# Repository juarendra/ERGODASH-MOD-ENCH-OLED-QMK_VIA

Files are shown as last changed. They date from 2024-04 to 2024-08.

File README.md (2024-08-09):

# Ergodash-Mod-QMK-VIA
This is MOD of ergodash, the normal ergodash just have Swith MX. This mod is for add Encoder, Oled and make it hotswapable with Khail Hotswap

## Table of Content
* [Product Specsification](#product-specsification)
* [Download VIA](#download-via)
* [Load JSON File](#Load-JSON-File)
* [Link Keycode QMK](#Link-keycode-qmk)
* [Tutorial VIA Usage](#tutorial-via-usage)
* [Cara Setting Knob](#cara-setting-knob)
* [How To use MACRO](#how-to-use-macro)
* [Preview Hardware](#preview-hardware)
* [Preview VIA](#preview-via)
* [Cara Update/Upgrade Firmware](#cara-update/upgrade-firmware)
* [Documentation](#documentation)
  * [Pinout Diagram](#pinout-diagram)
  * [Dimension](#dimension)
  * [BOM](#bom)
  * [Schematic](#schematic)
  * [Example Program](#examples-program)
* [FAQ](#FAQ)

## Product Specsification
- Arduino Pro Micro Type C as Microcontroller
- QMK Firmware
- Support VIA, all key and knob can proggrammed
- RGB Underglow
- 4x Layer 
- Hotswap Switch
- 3D Case 
- Ergodash Profile

## Download VIA
Link Download VIA(CHOSEE BASED YOUR OS) : https://github.com/the-via/releases/releases
VIA WEB VERSION : https://usevia.app/

## Load JSON File
or you can load manually json file like a library for detect this macropad
- Connect your macropad to PC
- Open VIA
- In Tab Setting, enable "Show Design Tab"
- Open Design Tab
- Load file with name "NEW_ErgoDash_4key_V3_mod_positron_elektronik.json" 
- Open Configure Tab to setting your macropad
- If nothing happend , do it again from first 

## Link Keycode QMK
- mouse : https://github.com/qmk/qmk_firmware/blob/master/docs/feature_mouse_keys.md
- keyboard : https://github.com/qmk/qmk_firmware/blob/master/docs/keycodes.md

## Tutorial VIA Usage
- https://docs.keeb.io/via

## Cara Setting Knob
- Untuk melakukan setting di knob perlu memasukan command berupa keycode qmk, Jadi cara nya sama dengan melakuykan setting dengan Any key seperti petunjuk pada link berikut: 
https://docs.keeb.io/via

Here's some examples:

- LALT(KC_TAB) - Sends Alt-Tab
- LCTL(KC_C) - Sends Ctrl-C
- LGUI(KC_C) - Sends Cmd-C or Win-C
- LSFT(LCTL(KC_END)) - Sends Shift-Ctrl-End
- MO(1) - Momentarily turn on layer 1
- LCA(KC_DEL) - Sends Ctrl-Alt-Del
- MT(MOD_RSFT, KC_ENT) - Sends Shift if held, Enter if tapped
- MACRO (0) - macro 0

## How To use MACRO
you can read on [this file](https://github.com/juarendra/STREAMPAD-QMK-VIA/blob/main/DOC/MACRO%20VIA%20USAGE.pdf)
or you can read on this [web](https://www.keychron.com/blogs/archived/how-to-use-via-to-program-your-keyboard)
or you can see video [youtube](https://youtu.be/GtSeo69Y0Zw)

## Preview Hardware
<p align="center">
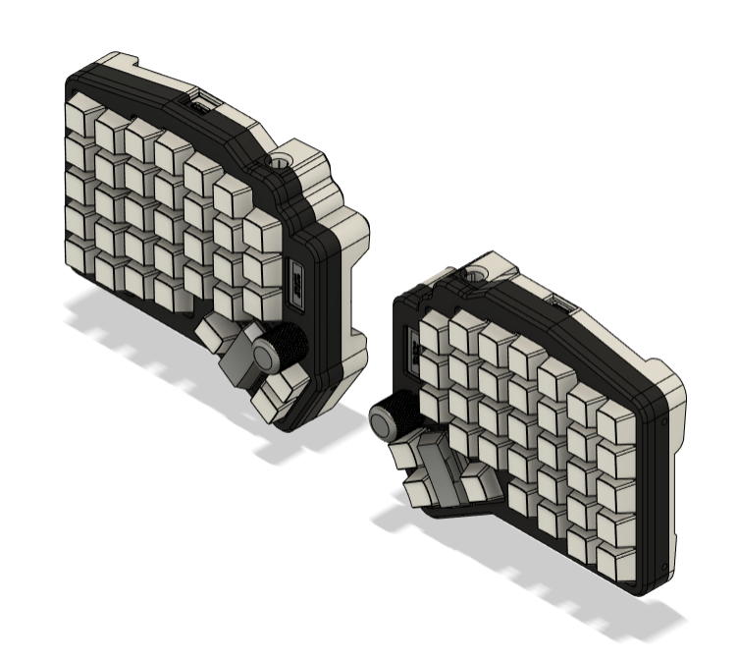
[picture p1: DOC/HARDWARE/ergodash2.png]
  
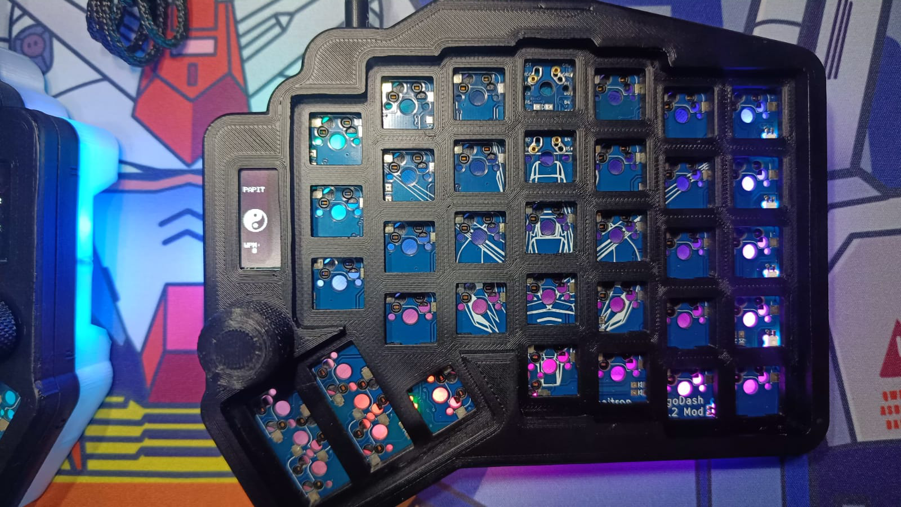
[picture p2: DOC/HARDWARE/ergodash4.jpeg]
  
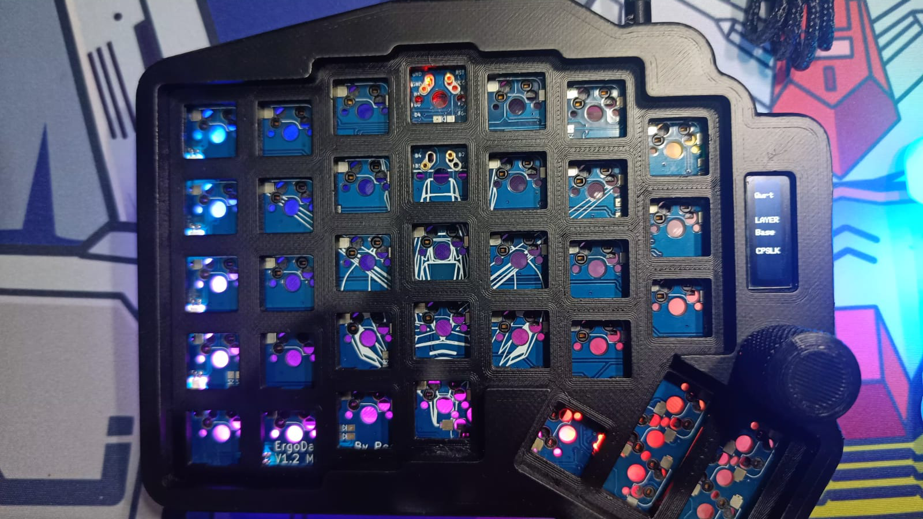
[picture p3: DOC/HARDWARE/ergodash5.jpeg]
  
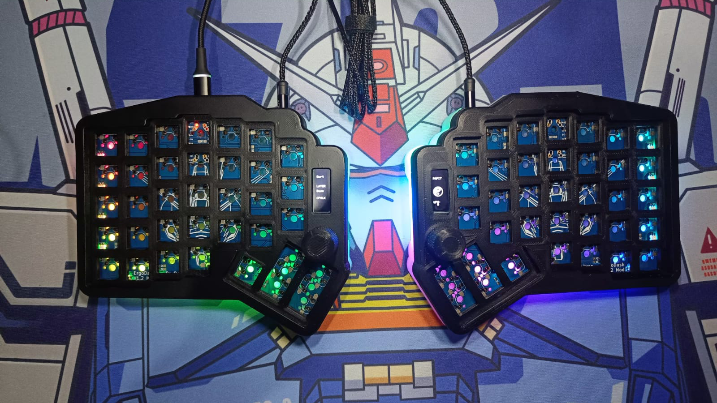
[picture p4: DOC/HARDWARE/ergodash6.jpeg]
  
</p>

## Preview VIA

https://github.com/juarendra/Zeapad-Pro-QMK-VIA/assets/43043633/afd7e68e-0a54-4b18-be12-b96c0f13611a

## Documentation
### Pinout Diagram
### Dimension
[Dimension File](https://github.com/juarendra/ERGODASH-MOD-ENCH-OLED-QMK_VIA/blob/main/Hardware/Dimension_Ergodash.pdf)
### BOM
### Schematic
[Schematic File](https://github.com/juarendra/ERGODASH-MOD-ENCH-OLED-QMK_VIA/blob/main/Hardware/ErgoDash_Schematic.pdf)
### Example Program
[Example Firmware](hhttps://github.com/juarendra/ERGODASH-MOD-ENCH-OLED-QMK_VIA/tree/main/FIRMWARE)
## FAQ

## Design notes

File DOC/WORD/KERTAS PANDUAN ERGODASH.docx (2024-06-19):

1. Untuk Documentasi Lengkapnya anda dapat membuka link google drive dibawah ini

https://github.com/juarendra/ERGODASH-MOD-ENCH-OLED-QMK_VIA

2. Lihat dahulu video untuk mengetahui cara pengunaan macropad dengan software VIA
3. Fungsi file file di google drive
a. Link Keycode.txt = berisi link yang menunjukan list keycode yang dapat digunakan dalam melakukan setting keymap
b. TUTORIAL MACRO ON VIA CONFIGURATOR.txt = berisi link tutorial cara membuat macro di software vial
c. LINK TUTORIAL PENGGUNAAN.txt = berisi link video tutorial penggunaan
d. TUTORIAL MEMBUAT TOMBOL PINDAH LAYER.txt = berisi panduan untuk merubah fungsi tombol sebagai trigger memindahkan layer
e. ErgoDash_mod_positron.json = json file untuk load di VIA

Untuk panduan lainnya menggunakan software via ada dapat membacanya disini https://docs.keeb.io/via

Pada via hanya dapat menyimpan maks 15 macro di seluruh layer. Ada beberapa trik untuk memaksimalkannya. Jika macro anda hanya kombinasi sederhana seperti CTRL + ALT + DEL maka anda dapat menggunakan fitur ANY keys pada tab special seperti dibawah

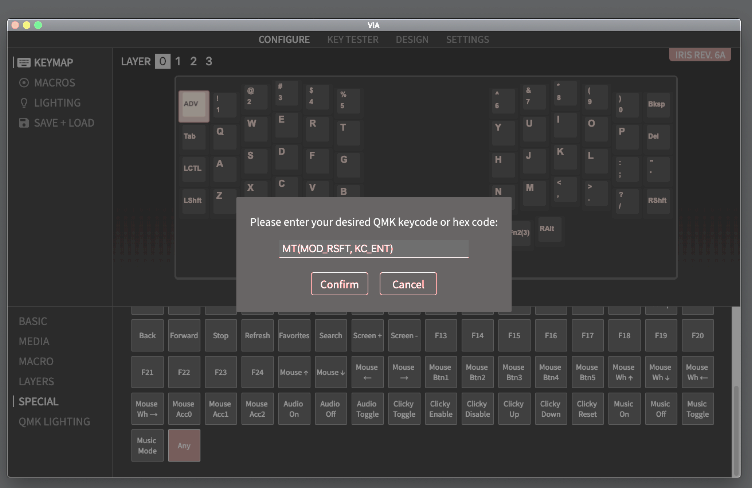
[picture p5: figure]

Untuk jelasnya anda dapat membacanya di https://docs.keeb.io/via

Cara Menggunakan Software VIA Pada Macropad

1. Colok dahulu Macropad pada PC
2. Buka Aplikasi VIA
3. Pada Tab Setting , aktifkan “Show Design Tab”
4. Buka Tan Design
5. Load file extension “ErgoDash_mod_positron.json” di google drive yang di berikan
6. Buka tab Configure untuk melakukan setting
7. Jika masih muncul gambar searching, maka ulangi lagi load json file

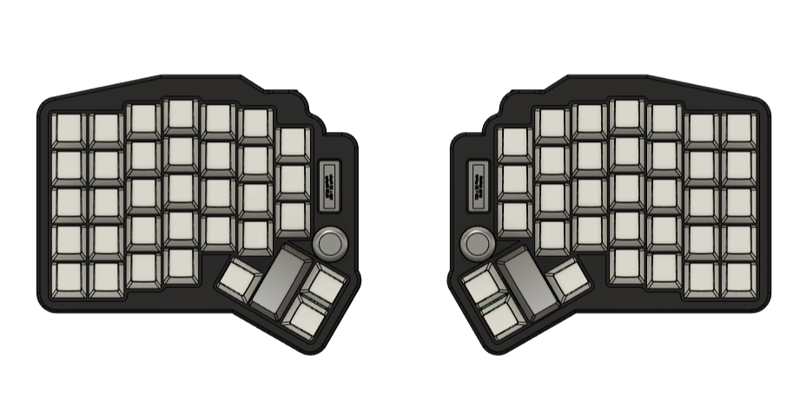
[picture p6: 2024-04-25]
DOC/HARDWARE/ergodash1.png

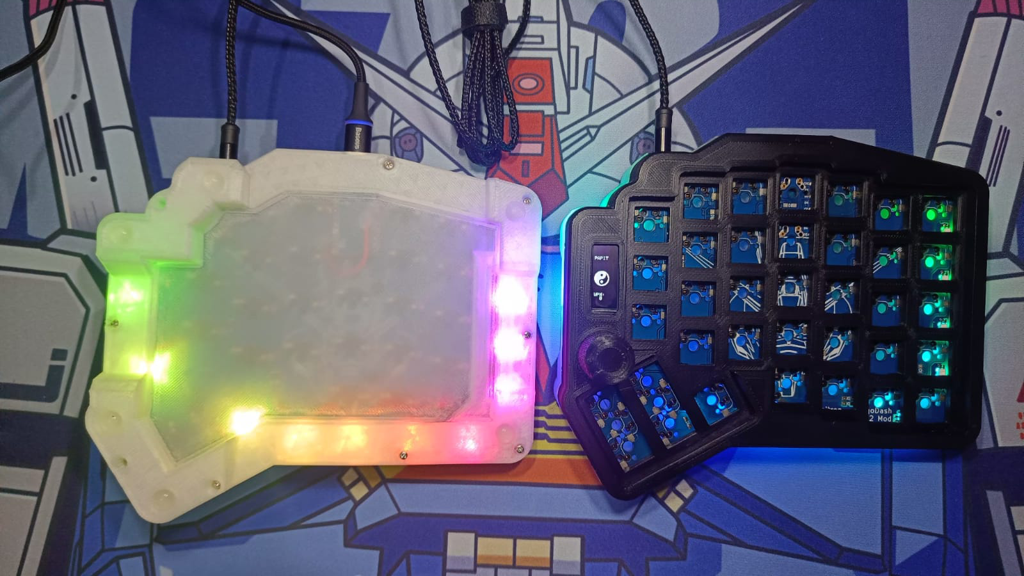
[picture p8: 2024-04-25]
DOC/HARDWARE/ergodash3.jpeg

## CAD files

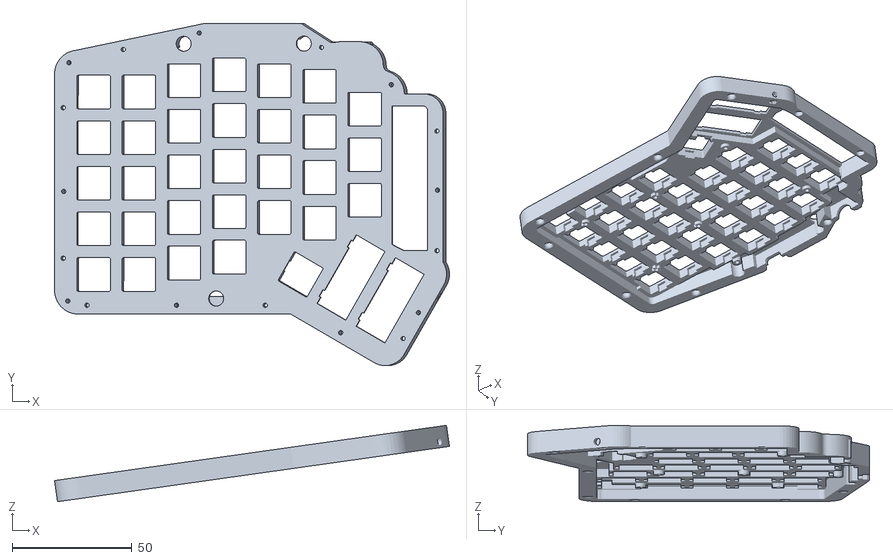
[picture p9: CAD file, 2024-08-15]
Hardware/3DCase/left/1. Ergodash_kiri_middle.stl
165.0 x 142.9 x 31.9

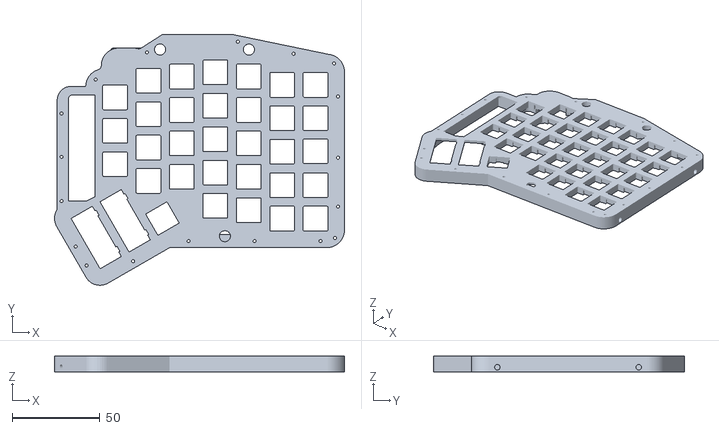
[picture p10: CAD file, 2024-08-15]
Hardware/3DCase/right/1. Ergodash_kanan_middle.stl
165.4 x 142.9 x 8.89

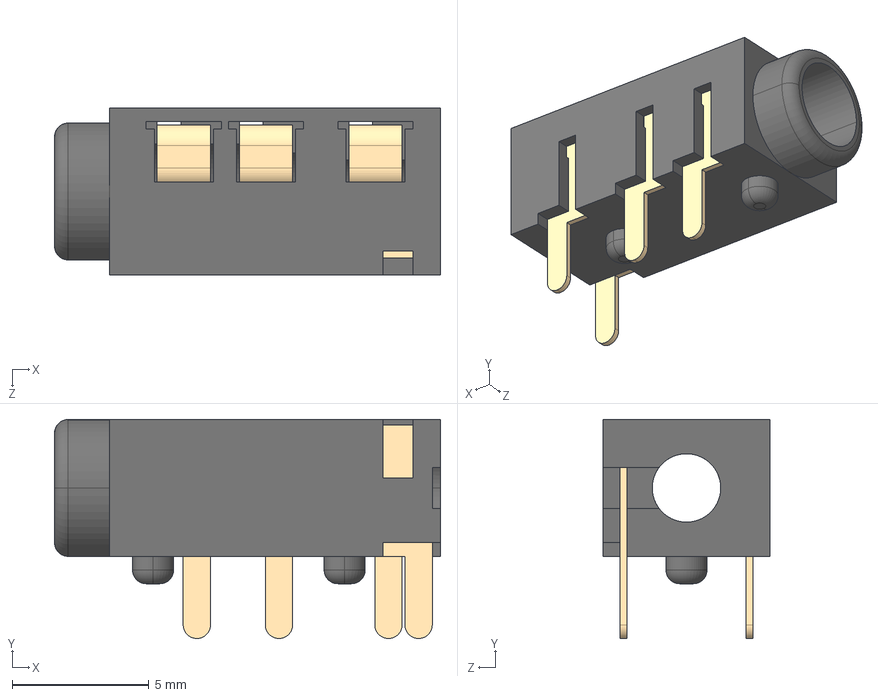
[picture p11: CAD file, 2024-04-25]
Hardware/PCB/Rev1.2/3d/PJ320A.STEP
14.1 x 8.00 x 6.10 mm
PJ320A蝶褲
PJ320A-Pin-A x 3
PJ320A-Pin-B

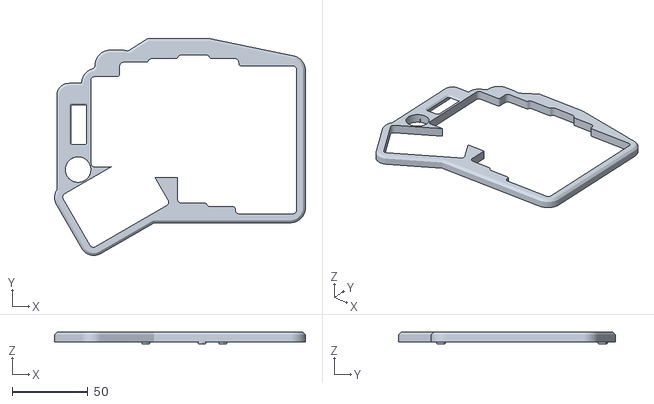
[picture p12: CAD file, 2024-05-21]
Hardware/3DCase/left/1. Ergodash_kiri_atas.stl
165.4 x 142.9 x 7.62

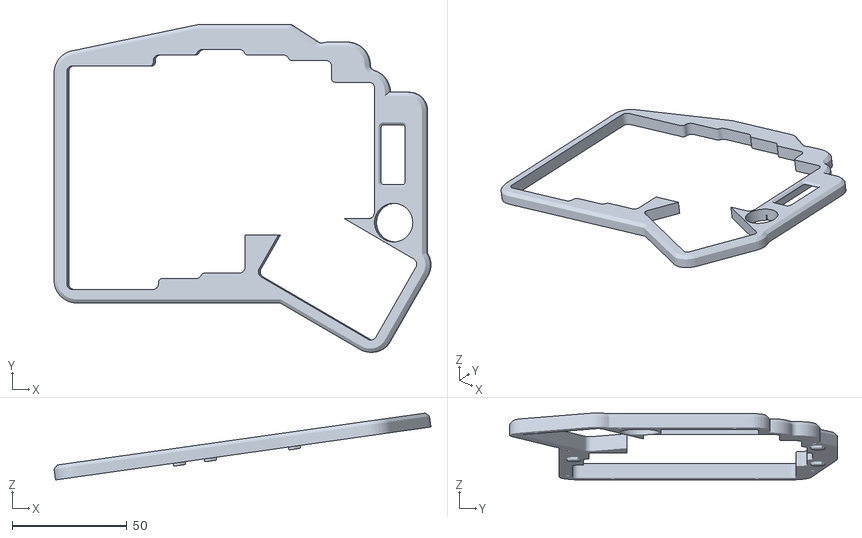
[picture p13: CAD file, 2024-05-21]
Hardware/3DCase/right/1. Ergodash_kanan_atas.stl
164.4 x 142.9 x 29.2

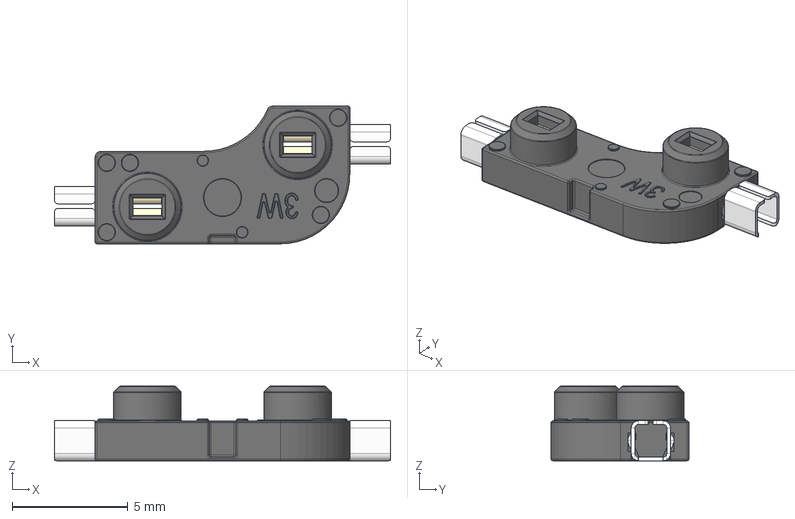
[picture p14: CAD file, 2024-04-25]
Hardware/PCB/Rev1.2/3d/Kailh Hotswap MX v22.step
14.5 x 5.95 x 3.22 mm

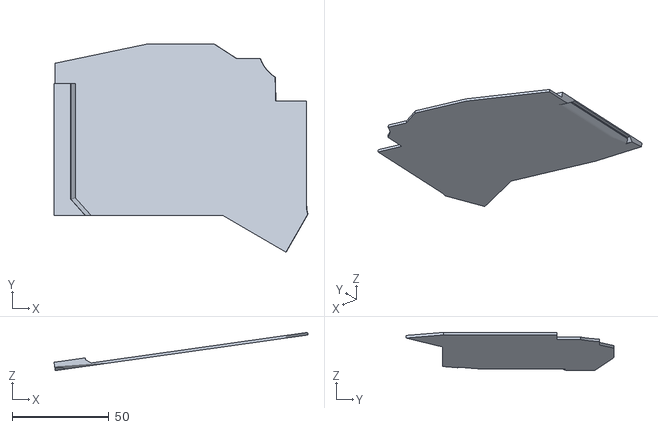
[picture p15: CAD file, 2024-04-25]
Hardware/3DCase/left/1. Ergodash_kiri_bottom2.stl
131.0 x 107.4 x 19.7

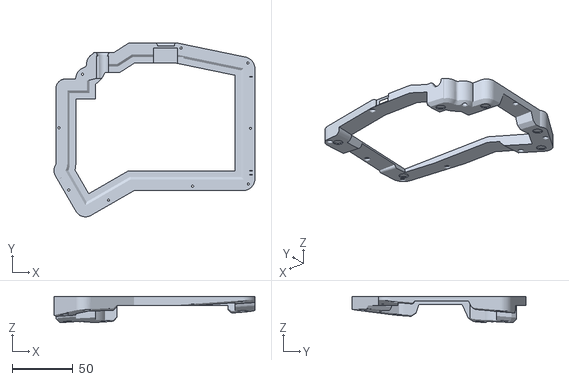
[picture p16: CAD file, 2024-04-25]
Hardware/3DCase/right/1. Ergodash_kanan_bottom1.stl
165.4 x 142.9 x 21.5

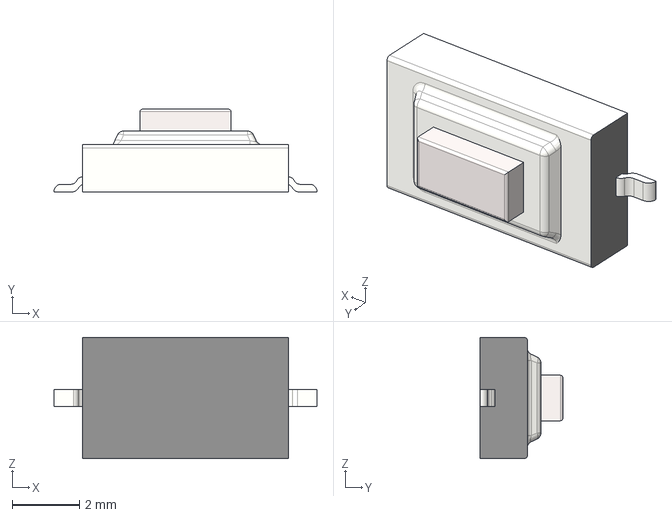
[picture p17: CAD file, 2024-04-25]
Hardware/PCB/Rev1.2/3d/TactileButton(6x3,5mm)_SMD.stp
7.80 x 2.45 x 3.60 mm

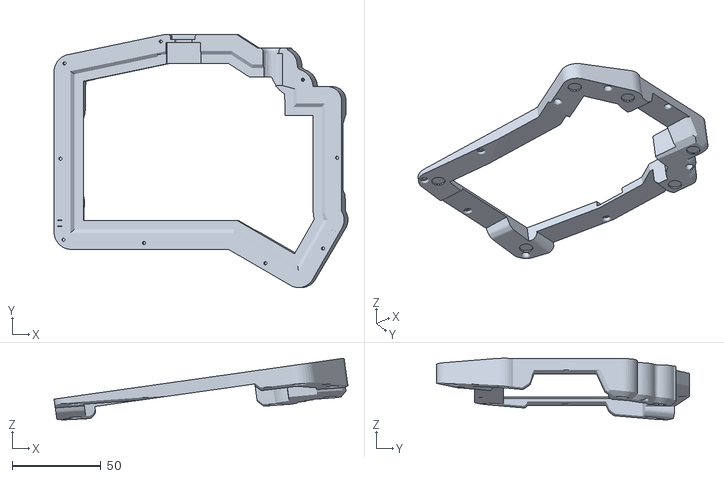
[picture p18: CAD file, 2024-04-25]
Hardware/3DCase/left/1. Ergodash_kiri_bottom1.stl
165.9 x 142.9 x 34.8

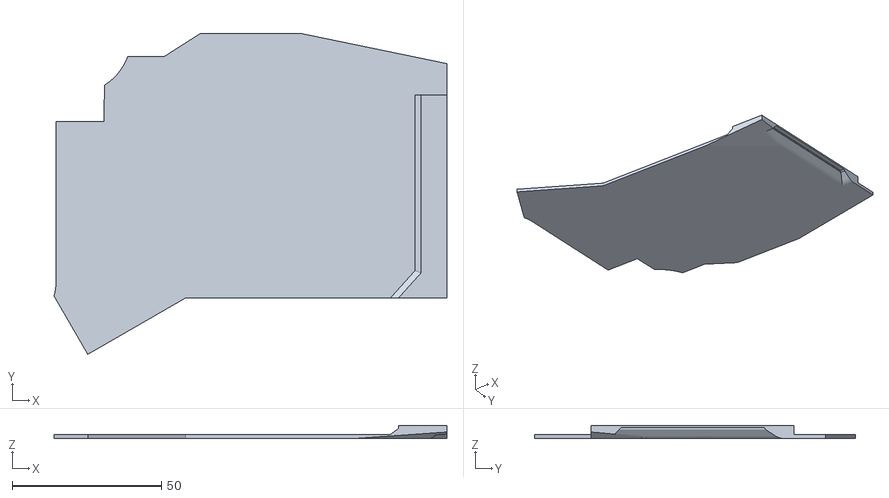
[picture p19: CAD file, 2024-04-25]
Hardware/3DCase/right/1. Ergodash_kanan_bottom2.stl
131.7 x 107.4 x 4.35

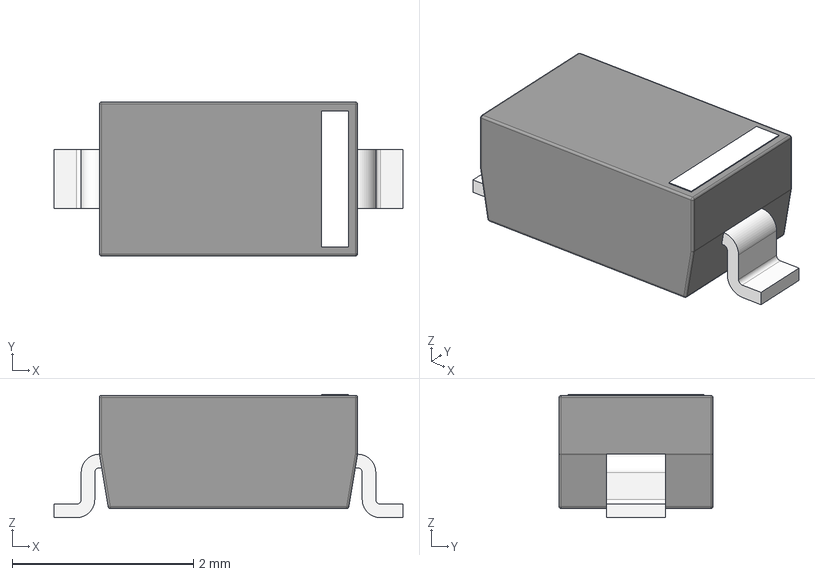
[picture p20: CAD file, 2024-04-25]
Hardware/PCB/Rev1.2/3d/SOD-123.step
3.85 x 1.70 x 1.36 mm

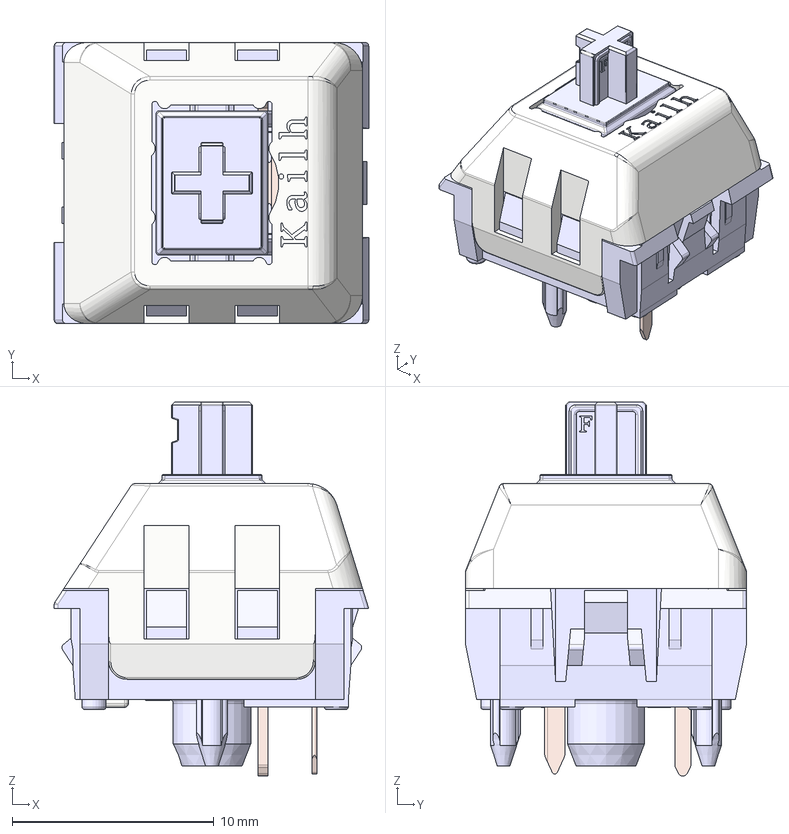
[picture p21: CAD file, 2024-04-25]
Hardware/PCB/Rev1.2/3d/Kailh Polia.step
15.6 x 14.0 x 18.5 mm
Housing
ThickContact
SpringContact
Stem
Lid

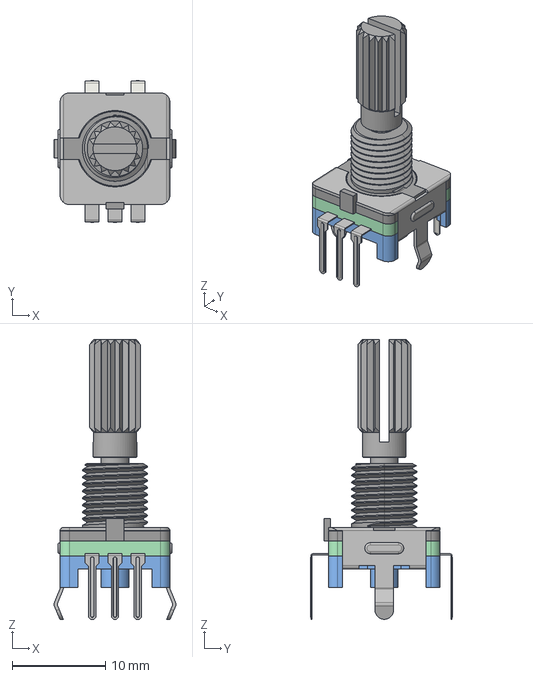
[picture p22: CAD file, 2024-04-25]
Hardware/PCB/Rev1.2/3d/EC11_Rotary_Encoder_Switched.step
13.1 x 15.3 x 30.1 mm

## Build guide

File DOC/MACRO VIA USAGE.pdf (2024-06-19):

MACRO
Pada VIA memiliki space yang terbatas atau jumlah macro yang tebatas. Maka dari itu untuk memaksimalkan penggunaan, anda dapat menggunkan Fitur Any Key jika macro anda hanya terdiri dari kombinasi yang sederhana. Untuk saat ini tidak ada batasan pada penggunaan Fitur Any Key
- MACRO NORMAL
Jika anda akan membuat macro dengan kombinasi yang rumit, anda dapat menggunakan macro yang ada pada tab/menu MACRO seperti gambar dibawah.
Macro Recorder

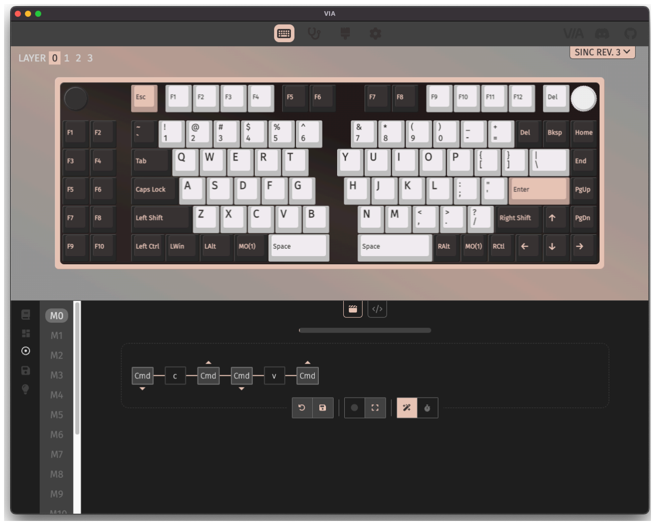
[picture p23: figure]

Metode ini memungkinkan Anda merekam makro, alih-alih mencoba mengetikkan kode kunci secara manual.
Keycode Entry

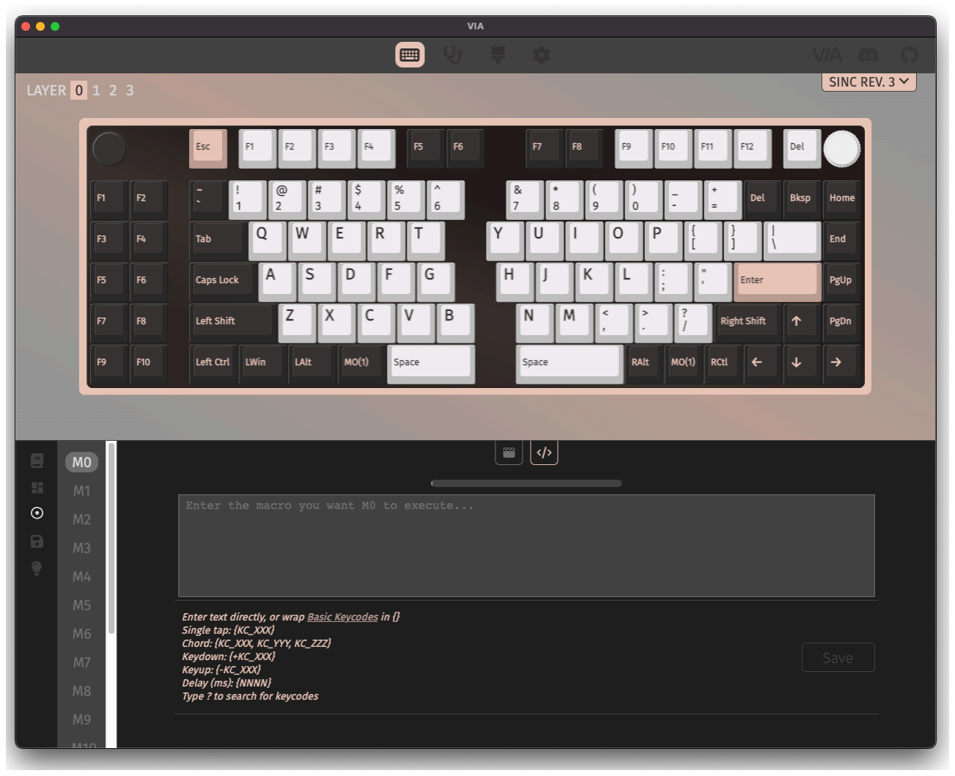
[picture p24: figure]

Anda bisa mengetik teks secara langsung tanpa harus mengetahui apa pun tentang nama keycodei QMK, atau jika Anda memasukkan sesuatu ke dalam tanda kurung kurawal ({}), Anda bisa menggunakan kode kunci QMK dasar.

Beberapa istilah yang perlu diketahui

MO (lapisan): Ini mengaktifkan lapisan ketika ditekan dan Anda kembali ke lapisan sebelumnya ketika Anda melepaskan kunci. Mirip dengan tombol Shift dan Fn dalam pengoperasiannya.

LM(layer, modifier): Ini mengaktifkan lapisan dan juga akan mempertahankan pengubah untuk Anda saat ditekan.

LT(lapisan, kode kunci): Tekan ini dan tahan untuk mengaktifkan lapisan dan mengirimkan kode kunci ketika diketuk sebentar. Penggunaan terbaik untuk tombol yang biasanya hanya Anda tekan dengan cepat seperti Tab atau Spasi.

Contoh Makro
MyPassw0rd! - Mengirim MyPassw0rd!
{KC_A,KC_C,KC_E} - Mengirim kartu as
{KC_LCTL,KC_C} - Mengirim Ctrl-C
- Any Key
Any Key dapat digunakan untuk melakukan beberapa kode kunci yang lebih kompleks, seperti yang melibatkan pengubah, lapisan, atau tombol ketuk mod. Anda juga dapat memasukkan kode kunci biasa di sini jika Anda mau.

Tidak semua alias didukung, misalnya LCTL_T(kc) tidak dapat digunakan, jadi MT(MOD_LCTL, kc) harus digunakan.

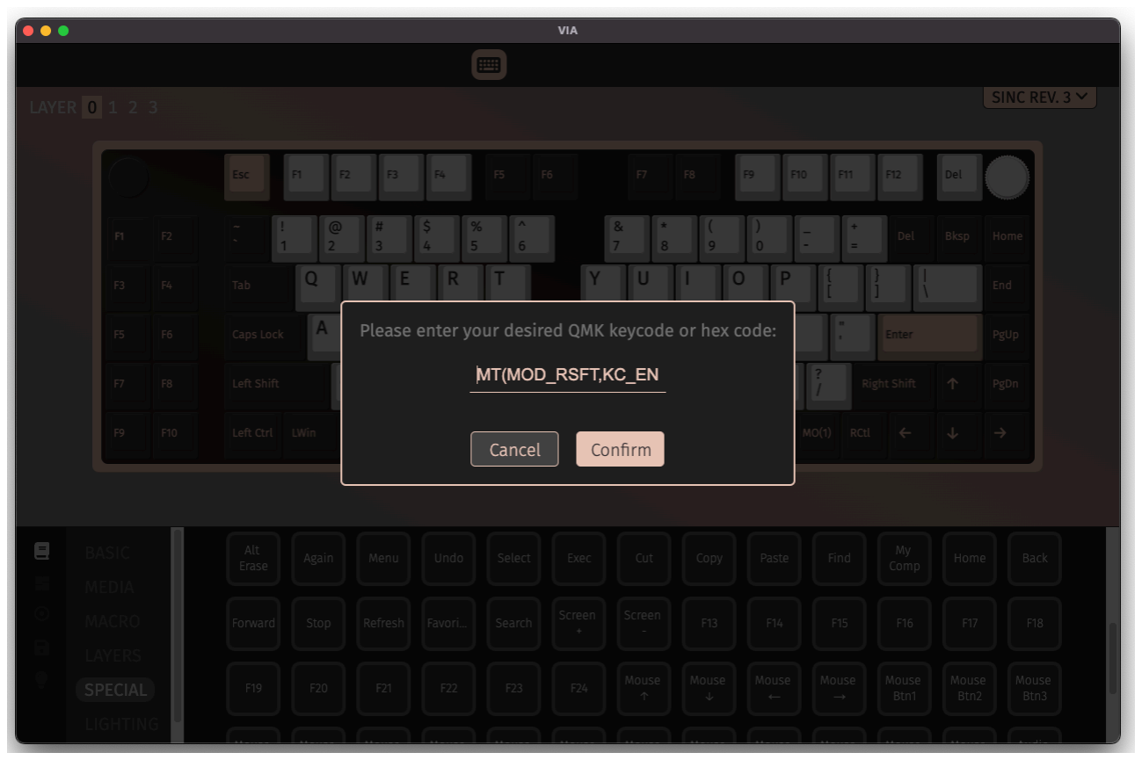
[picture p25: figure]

Here's some examples:

LALT(KC_TAB) - Sends Alt-Tab
LCTL(KC_C) - Sends Ctrl-C
LGUI(KC_C) - Sends Cmd-C or Win-C LSFT(LCTL(KC_END)) - Sends Shift-Ctrl-End
MO(1) - Momentarily turn on layer 1
LCA(KC_DEL) - Sends Ctrl-Alt-Del
MT(MOD_RSFT, KC_ENT) - Sends Shift if held, Enter if tapped QMK Lighting

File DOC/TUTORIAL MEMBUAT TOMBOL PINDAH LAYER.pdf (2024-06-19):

1. Buka App VIA Configurator
2. Masukan File JSON keymap yang ada di google drive
3. Hubungkan Macropad ke PC
4. Buka Tab Configure
5. Pada Tab Configure pilih Tab Layer
6. Tentukan 1 Tombol yang akan digunakan untuk perpindahan layer
7. Ketika baru pertama dihubungkan ke PC maka macropad otomatis berada pada layer 0, 8. Klick tombol tersebut dan ganti fungsi menjadi TO1(isi dari tab layer), ini artinya fungsi tombol

tersebut adalah memidahkan layer sekarang ke layer 1
9. Pindah ke layer 1, lalu klick tombol tersebut lagi dan ganti fungsi menjadi TO2(isi dari tab layer), ini artinya fungsi tombol tersebut adalah memidahkan layer sekarang ke layer 2 10.Pindah ke layer 2, lalu klick tombol tersebut lagi dan ganti fungsi menjadi TO3(isi dari tab layer), ini artinya fungsi tombol tersebut adalah memidahkan layer sekarang ke layer 3
11. Pindah ke layer 3, lalu klick tombol tersebut lagi dan ganti fungsi menjadi TO0(isi dari tab layer), ini artinya fungsi tombol tersebut adalah memindahkan layer sekarang kembali lagi ke layer 0
12. Selesai

layer 0 ----> layer 1 ----> layer 2 ----> layer 3 ----> layer 0
TO1 | TO2 | TO3 | TO0

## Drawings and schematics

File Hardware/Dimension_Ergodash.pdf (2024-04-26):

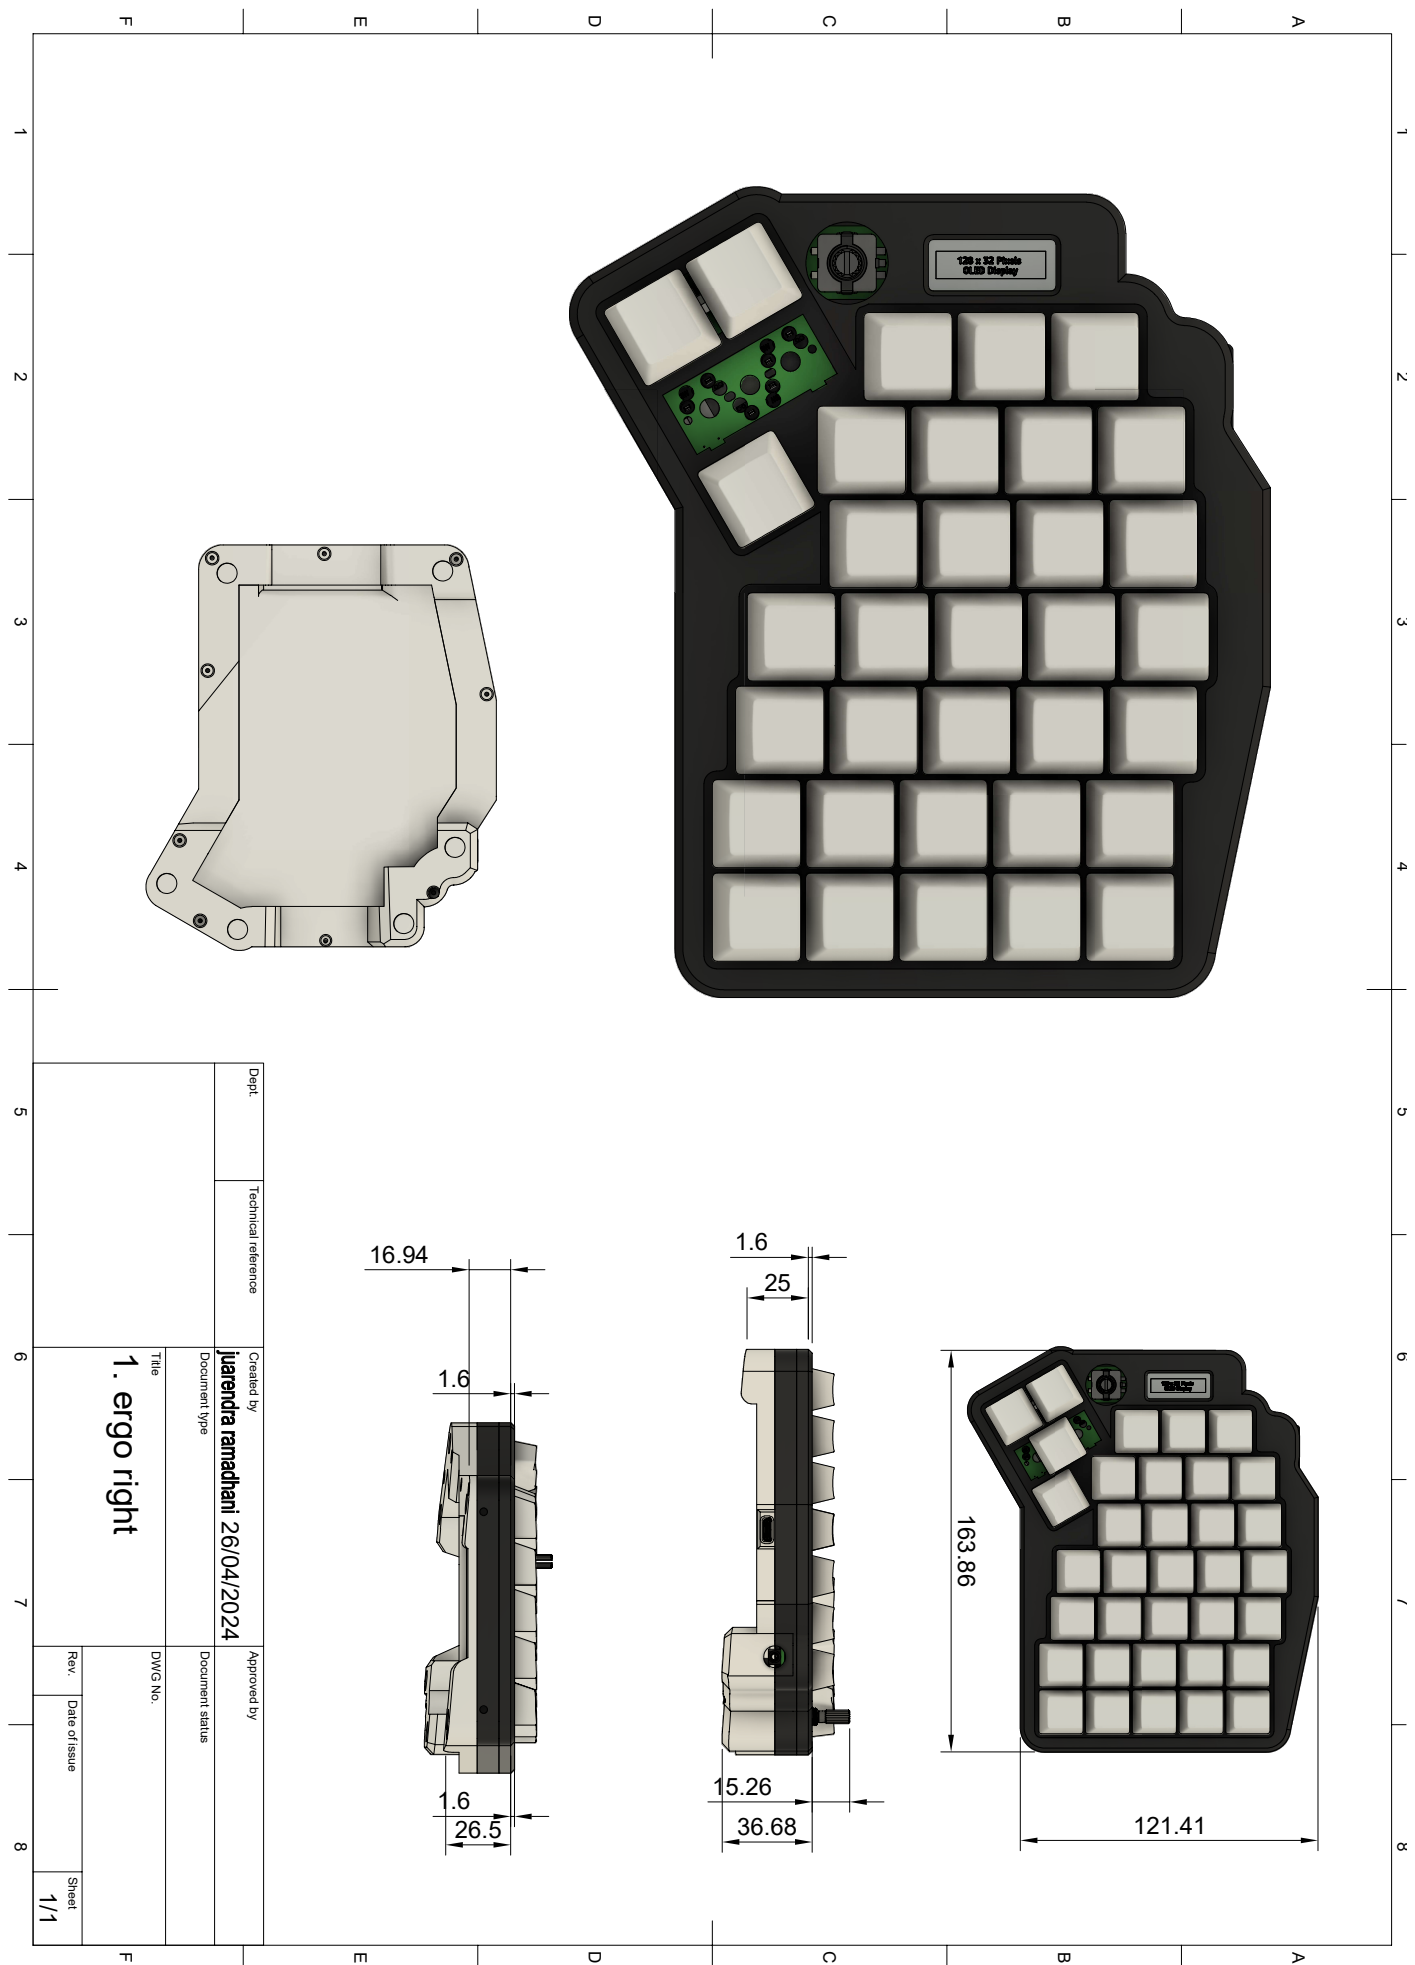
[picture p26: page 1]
121.41 ¹⁶³.86

1 A 2 3 4 5 6 7 8 1 2 3 4 5 6 7 8 FEDCB FEDCBA Dept. Technical reference Created by Approved by Title DWG No. Document type Document status Rev. Date of issue Sheet 26/04/2024 1/1 1. ergo right

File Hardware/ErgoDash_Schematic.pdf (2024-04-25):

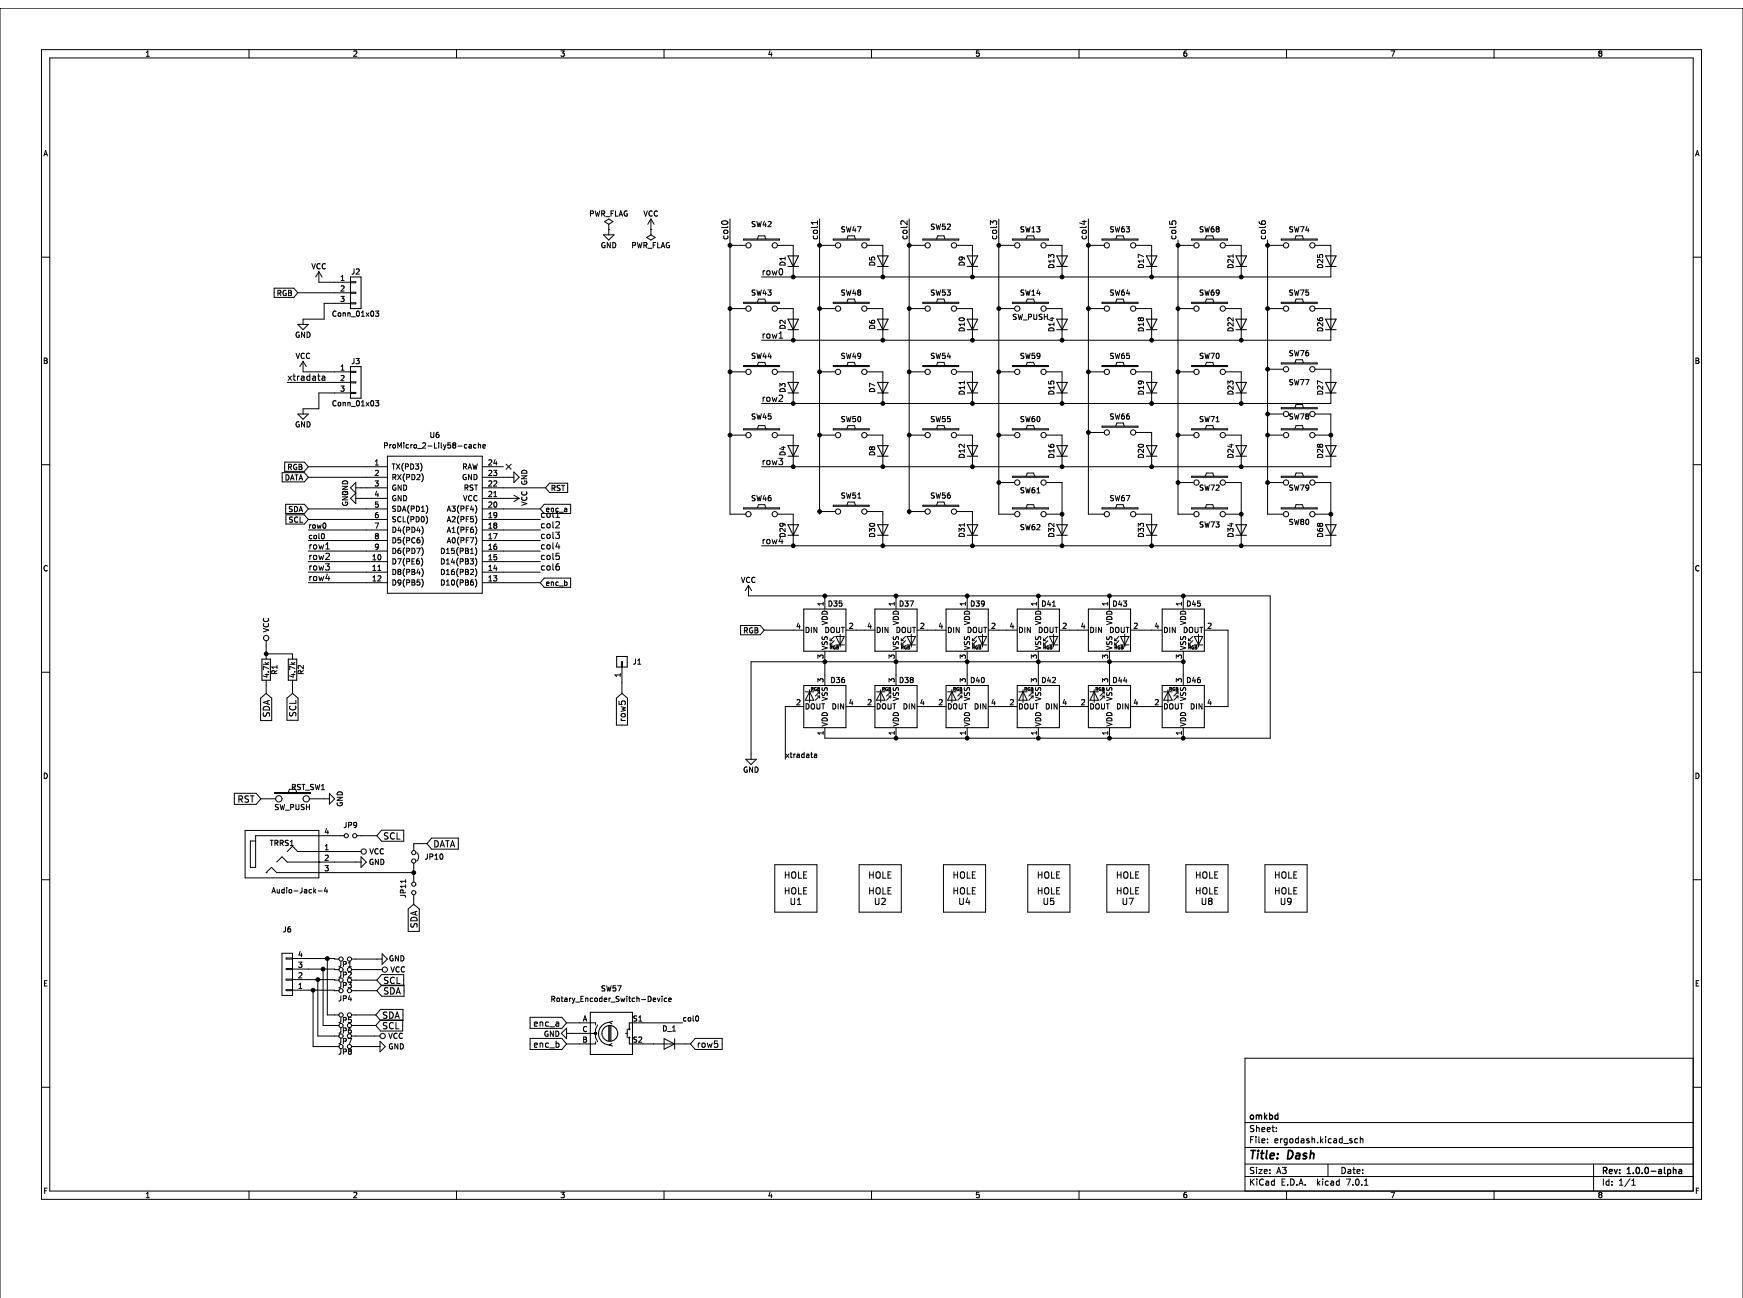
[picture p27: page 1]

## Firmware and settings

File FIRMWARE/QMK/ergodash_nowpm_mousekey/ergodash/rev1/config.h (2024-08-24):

/* Copyright 2024 Juarendra Ramadhani <jrjuarendra@gmail.com>
 *
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
 * You should have received a copy of the GNU General Public License
 * along with this program.  If not, see <http://www.gnu.org/licenses/>.
 */

#pragma once


/* key matrix size */
// Rows are doubled-up
#define MATRIX_ROWS 12
#define MATRIX_COLS 7

// wiring of each half
#define MATRIX_ROW_PINS { D4, D7, E6, B4, B5 , B0}
#define MATRIX_COL_PINS { C6, F5, F6, F7, B1, B3, B2 }
// #define MATRIX_COL_PINS { B2, B3, B1, F7, F6, F5, F4 } //uncomment this line and comment line above if you need to reverse left-to-right key order

#define DIODE_DIRECTION COL2ROW

/* define tapping term */
#define TAPPING_TERM 120

/* Set 0 if debouncing isn't needed */
#define DEBOUNCE 5

/* Mechanical locking support. Use KC_LCAP, KC_LNUM or KC_LSCR instead in keymap */
#define LOCKING_SUPPORT_ENABLE
/* Locking resynchronize hack */
#define LOCKING_RESYNC_ENABLE

#define ENCODERS_PAD_A { F4 }
#define ENCODERS_PAD_B { B6 }
#define ENCODER_RESOLUTIONS_RIGHT 2 
#define ENCODER_RESOLUTION 4 	
#define TAP_CODE_DELAY  10

// Add RGB underglow
// by defining in the keyboard, incompatible keymaps will fail to compile.
#ifdef RGBLIGHT_ENABLE
#    define WS2812_DI_PIN D3
#    define RGBLED_NUM 24
#    define RGBLED_SPLIT {12,12}
#    define RGBLIGHT_LIMIT_VAL 100 // LED Brightness, high power draw may exceed the USB limitations of 0.6A and cause a crash.
#    define RGBLIGHT_HUE_STEP  10
#    define RGBLIGHT_SAT_STEP  17
#    define RGBLIGHT_VAL_STEP  17
//#    define RGBLIGHT_LAYERS //Enable layer light indicators. Not required as updates are done in layer_state_set_user and led_update_user (+588).
#    define RGBLIGHT_SLEEP //Turn off LEDs when computer sleeping (+72)
#endif

#define SOFT_SERIAL_PIN D2
#define SPLIT_USB_DETECT

// OLED settings
#define OLED_TIMEOUT    80000
#define OLED_BRIGHTNESS 90

//#define SPLIT_WPM_ENABLE
#define SPLIT_OLED_ENABLE
#define SPLIT_TRANSPORT_MIRROR

#ifdef RGBLIGHT_ENABLE
#    define RGBLIGHT_DEFAULT_MODE RGBLIGHT_EFFECT_STATIC_GRADIENT +2

// Disabling some of these is a good way to save flash space.
//#    define RGBLIGHT_EFFECT_ALTERNATING     // 108
#    define RGBLIGHT_EFFECT_RAINBOW_MOOD    // 160
#    define RGBLIGHT_EFFECT_STATIC_GRADIENT // 168
#    define RGBLIGHT_EFFECT_RAINBOW_SWIRL   // 192
#    define RGBLIGHT_EFFECT_BREATHING       // 348
//#    define RGBLIGHT_EFFECT_KNIGHT          // 336
//#    define RGBLIGHT_EFFECT_SNAKE           // 406
#endif

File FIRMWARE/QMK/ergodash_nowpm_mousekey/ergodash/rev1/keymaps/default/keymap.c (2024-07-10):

/* Copyright 2024 Juarendra Ramadhani <jrjuarendra@gmail.com>
 *
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
 * You should have received a copy of the GNU General Public License
 * along with this program.  If not, see <http://www.gnu.org/licenses/>.
 */
#include QMK_KEYBOARD_H

#include "oled.c"

// Base layer is the number of layers CYCLE selects from.
#define BASE_LAYERS 2

enum custom_keycodes {
    PLACEHOLDER = SAFE_RANGE,  // can always be here (4 bytes)
    CYCLE                      // cycle through first BASE_LAYERS (62 bytes)
};

enum custom_layers {
    _QWERTY,
    _COLEMAK,
    _LOWER,
    _RAISE
};


const uint16_t PROGMEM keymaps[][MATRIX_ROWS][MATRIX_COLS] = {

  /* Qwerty
   * ,----------------------------------------------------------------------------------------------------------------------.
   * | ESC  |   1  |   2  |   3  |   4  |   5  |   [  |                    |   ]  |   6  |   7  |   8  |   9  |   0  |Pscree|
   * |------+------+------+------+------+------+------+--------------------+------+------+------+------+------+------+------|
   * |  `   |   Q  |   W  |   E  |   R  |   T  |   -  |                    |   =  |   Y  |   U  |   I  |   O  |   P  |  \   |
   * |------+------+------+------+------+------+------+--------------------+------+------+------+------+------+------+------|
   * | Tab  |   A  |   S  |   D  |   F  |   G  |  Del |                    | Bksp |   H  |   J  |   K  |   L  |   ;  |  "   |
   * |------+------+------+------+------+------+---------------------------+------+------+------+------+------+------+------|
   * | Shift|   Z  |   X  |   C  |   V  |   B  | Space|                    | Enter|   N  |   M  |   ,  |   .  |   /  | Shift|
   * |-------------+------+------+------+------+------+------+------+------+------+------+------+------+------+-------------|
   * | Ctrl |  GUI |  ALt | EISU |||||||| Lower| Space|  Del |||||||| Bksp | Enter| Raise|||||||| Left | Down |  Up  | Right|
   * ,----------------------------------------------------------------------------------------------------------------------.
   */
  [_QWERTY] = LAYOUT(
    KC_ESC,  KC_1,    KC_2,    KC_3,    KC_4,    KC_5,    KC_LBRC,                        KC_RBRC, KC_6,    KC_7,    KC_8,    KC_9,    KC_0,    KC_PSCR,
    KC_GRV,  KC_Q,    KC_W,    KC_E,    KC_R,    KC_T,    KC_MINS,                        KC_EQL , KC_Y,    KC_U,    KC_I,    KC_O,    KC_P,    KC_BSLS,
    KC_TAB,  KC_A,    KC_S,    KC_D,    KC_F,    KC_G,    KC_DEL ,                        KC_BSPC, KC_H,    KC_J,    KC_K,    KC_L,    KC_SCLN, KC_QUOT,
    KC_LSFT, KC_Z,    KC_X,    KC_C,    KC_V,    KC_B,    KC_SPC ,                        KC_ENT , KC_N,    KC_M,    KC_COMM, KC_DOT,  KC_SLSH, KC_RSFT,
    KC_LCTL, KC_LGUI, KC_LALT, KC_C,             MO(_LOWER),   KC_A ,KC_DEL,         KC_BSPC,KC_B , MO(_RAISE),            KC_LEFT, KC_DOWN, KC_UP,   KC_RGHT,
    KC_A, KC_B, KC_C, KC_D, KC_E, KC_F
  ),

  
  /* Adjust
   * ,----------------------------------------------------------------------------------------------------------------------.
   * |      |      |      |      |      |      |      |                    |      |      |      |      |      |      |      |
   * |------+------+------+------+------+------+---------------------------+------+------+------+------+------+------+------|
   * |      | Reset|RGB ON|  MODE|  HUE-|  HUE+|      |                    |      |  SAT-|  SAT+|  VAL-|  VAL+|      |      |
   * |------+------+------+------+------+------+---------------------------+------+------+------+------+------+------+------|
   * |      |      | BL ON|  BRTG|  INC|   DEC|      |                    |      |      |      |      |      |      |      |
   * |------+------+------+------+------+------+---------------------------+------+------+------+------+------+------+------|
   * |      |      |      |      |      |      |      |                    |      |      |      |      |      |      |      |
   * |-------------+------+------+------+------+------+------+------+------+------+------+------+------+------+-------------|
   * |      |      |      |      ||||||||      |      |      ||||||||      |      |      ||||||||      |      |      |      |
   * ,----------------------------------------------------------------------------------------------------------------------.
   */
  [_COLEMAK] = LAYOUT(
    _______, _______, _______, _______, _______, _______,_______,                       _______, _______, _______, _______, _______, _______, _______,
    _______, QK_BOOT  , RGB_TOG, RGB_MOD, RGB_HUD, RGB_HUI,_______,                       _______, RGB_SAD, RGB_SAI, RGB_VAD, RGB_VAI, _______, _______,
    _______, _______, BL_TOGG, BL_BRTG, BL_UP  , BL_DOWN,_______,                       _______, _______, _______, _______, _______, _______, _______,
    _______, _______, _______, _______, _______, _______,_______,                       _______, _______, _______, _______, _______, _______, _______,
    _______, _______, _______, _______,          _______,_______,_______,       _______,_______, _______,          _______, _______, _______, _______,
    KC_A, KC_B, KC_C, KC_D, KC_E, KC_F
  ),
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

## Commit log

2024-05-03 FEAT: update file case middle
    [1. Ergodash_kiri_middle.stl]
2024-05-21 FIX: fix there no hole for bolt bottom case to middle case
    [1. Ergodash_kanan_atas.stl, 1. Ergodash_kiri_atas.stl]
2024-08-09 FEAT: add encoder right resolution
2024-08-15 FEAT: update case for some isues
    [1. Ergodash_kanan_middle.stl, 1. Ergodash_kiri_middle.stl]
2026-10-09 feat: ENCHDASH compliance and identity remediation
    Add comprehensive licensing, attribution, and provenance tracking
    for ENCHDASH (formerly ERGODASH-MOD-ENCH-OLED-QMK_VIA).
    ## Changes
    - Add LICENSE index and full license texts (MIT hardware, GPL firmware)
    - Create firmware provenance manifest with SHA-256 checksums
    - Establish legacy support documentation for existing units
    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
2026-10-10 chore: bound doc claims and resolve footprint license provenance
    Complete the review-remediation contract and audit hardware footprint
    licensing. No firmware, VIA JSON, QMK source, or PCB geometry changed.
    Docs
    - Bound unbounded device-behavior claims ("works exactly as before",
    "remains fully supported") to repo-provable wording across
    DEPLOYMENT-REPORT, RELEASE-CHECKLIST, IMPLEMENTATION-SUMMARY, QUICKSTART
    - Fix stale validator section counts (sections 1-6 -> all 7 sections)
    - Label historical "16 of 21 tasks" count as the 2026-10-08 plan
    Hardware footprint audit (2026-10-10)
    - Parsed ergodash.kicad_pcb (119 footprint instances)
    - Remove 4 zero-reference vendored libs: Keebio-Parts.p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
2026-10-10 docs: document SK6812 footprint license position (datasheet geometry)
    Record the owner-accepted position for prettylib:SK6812_mini_e_flipable
    (12 instances): pad/slot geometry follows the SK6812MINI-E datasheet and
    is treated as functional/factual, not a copyrightable work, so no GPL-3.0
    obligation propagates from upstream yaemk-split-kb. Upstream GPL-3.0 is
    credited, and an upgrade path (swap to a permissive SK6812 footprint, or
    vendor the GPL-3.0 lib) is noted. PCB unchanged.
    Validation: 20/20 unit tests, validator 7/7 sections exit 0
2026-10-10 docs: document 3D models as visualization-only (non-blocking provenance)
    Record the owner-accepted position for the STEP models in
    Hardware/PCB/Rev1.2/3d/: they are used only by KiCad's 3D viewer, are
    excluded from gerber manufacturing output and the shipped product, and
    depict commodity parts. Vendor provenance is therefore treated as
    non-blocking for distribution; KiCad standard models ship under the KiCad
    library license. Upgrade path (remove 3d/ with zero PCB impact) noted.
    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
2026-10-10 docs: license owner-created works under MIT (VIA JSON, docs, media)
    Owner confirmed authorship and chose MIT for owner-created content.
    - Add LICENSES/MIT-ENCHDASH.txt (Copyright (c) 2024-2026 Juarendra
    Ramadhani)
    - THIRD_PARTY_NOTICES.md: VIA JSON definitions and media (hardware
    photos, tutorial video, user manuals) now owner-confirmed and
    MIT-licensed; update compliance status and resolved-items list
    - LICENSE index item 4 now points to MIT-ENCHDASH.txt
    Resolves the VIA JSON licensing and media authorship gaps. Remaining
    items (QMK build provenance, device test, KiCad evidence, own VID/PID)
    are toolchain/hardware-gated, not documentation gaps.
    Validation: 20/20 unit tests, validato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
2026-10-10 docs: rebrand user manuals and add architecture diagrams
    - Regenerate DOC/*.pdf as branded Positron Electronic / ENCHDASH manuals
    via tools/generate_manuals.py (consistent header/footer identity, teal
    accent, hardware photos). Content preserved from the originals but
    reference-corrected: canonical VIA JSON
    (NEW_ErgoDash_4key_V3_mod_positron_elektronik.json), GitHub repo URL,
    ENCHDASH naming, working VIA docs link.
    - README.md: add Architecture section with four Mermaid diagrams (split
    topology/data flow, layer state model, firmware feature map,
    keymap->VIA JSON->firmware mapping). All four validated via mermaid.parse.
    - Add .gitattributes marking binary assets (PDF/MOV/HEX/imag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
2026-10-10 docs: record owner attestation for device test and KiCad gates
    Owner (Positron Electronic) confirms the ENCHDASH was flashed, enumerated,
    VIA-detected, smoke-tested, and fabricated into shipping product, and that the
    Rev1.2 PCB passes ERC/DRC with Gerbers matching production.
    - Add docs/evidence/device-test.md (Gate 4 attestation: USB enumeration, VIA
    detection, key/encoder/OLED/RGB/split checks).
    - Rewrite docs/evidence/kicad-owner-verification.md as Gate 6 owner attestation
    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
2026-10-10 feat: migrate USB identity to pid.codes 0x1209:0x2013
    Replace legacy upstream VID/PID 0x4D44:0x6061 with the project-owned
    pid.codes allocation 0x1209:0x2013 (org Positron-Electronic). Registration
    PR: pidcodes/pidcodes.github.com#1303.
    - Swap vendorId/productId in both VIA JSONs and usb.vid/pid in all four
    FIRMWARE/QMK/**/rev1/info.json.
    - Rebuild the three shipped .hex from source (QMK 0.26.11, avr-gcc 15.1.0)
    carrying the new identity; USB descriptor byte-scan confirms 0x1209:0x2013
    and no legacy 0x4D44:0x6061. Shipped sha256 == rebuilt_sha256.
    - Update FIRMWARE/manifest.json, FIRMWARE/README.md, README.md,
    docs/LEGACY-SUPPORT.md, docs/HARDWARE-ATTRIBUTION.md,
    docs/evidence/qmk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
2026-10-10 docs: update repository URLs for ENCHDASH-QMK-VIA rename
    Rename GitHub repository ERGODASH-MOD-ENCH-OLED-QMK_VIA -> ENCHDASH-QMK-VIA
    and update all hardcoded repository URLs in docs and tooling to the new
    canonical URL (https://github.com/juarendra/ENCHDASH-QMK-VIA).
    - README.md, FIRMWARE/README.md, THIRD_PARTY_NOTICES.md,
    docs/HARDWARE-ATTRIBUTION.md, QUICKSTART.md, CHANGELOG.md contact URL.
    - tools/generate_manuals.py REPO_URL constant.
    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

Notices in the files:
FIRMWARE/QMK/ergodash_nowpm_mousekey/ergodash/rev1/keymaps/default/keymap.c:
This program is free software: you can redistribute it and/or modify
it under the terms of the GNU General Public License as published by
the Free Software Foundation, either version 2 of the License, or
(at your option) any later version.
